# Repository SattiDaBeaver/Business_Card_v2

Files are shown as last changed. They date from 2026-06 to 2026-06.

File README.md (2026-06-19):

# RISC-V Supercluster Business Card

A business-card-sized PCB featuring a miniature distributed compute cluster with one master MCU coordinating eight worker nodes over a shared UART bus, powered and programmed entirely through a PCB-edge USB-C connector.

Inspired by distributed systems, Network-on-Chip architectures, and AI accelerator fabrics — shrunk down to fit in a wallet.

## Architecture

- **1× CH32X035F7P6** (master) — RV32IMAC, native USB 2.0 + USB PD PHY, USB CDC terminal, command parser, task scheduler, packet router
- **8× CH32V006F4P6** (workers) — RV32EC, distributed task execution, per-node LED, packet forwarding

## Communication

Workers and master share a half-duplex, open-drain UART bus (`BUS_MOSI` / `BUS_MISO`) with pull-up resistors to prevent contention. A simple addressed packet protocol (STX/DST/SRC/CMD/LEN/PAYLOAD/CRC8/ETX) handles routing, pings, LED control, and distributed compute tasks.

The master can individually reset and reflash any worker over UART using its factory bootloader — no physical programmer access needed after initial setup.

## Hardware Features

- USB-C via PCB edge connector (0.8mm board, no connector part needed)
- Shared 3.3V rail (AMS1117-3.3 LDO)
- Per-node SWIO/SDI debug pads for direct programming/recovery
- Individual master-controlled NRST per worker node
- Exposed GPIO test point grid on the reverse side

## Programming

- **Master:** USB bootloader or SWIO via WCH-LinkE
- **Workers:** SWIO via WCH-LinkE (initial flash) or UART bootloader via master (field updates)

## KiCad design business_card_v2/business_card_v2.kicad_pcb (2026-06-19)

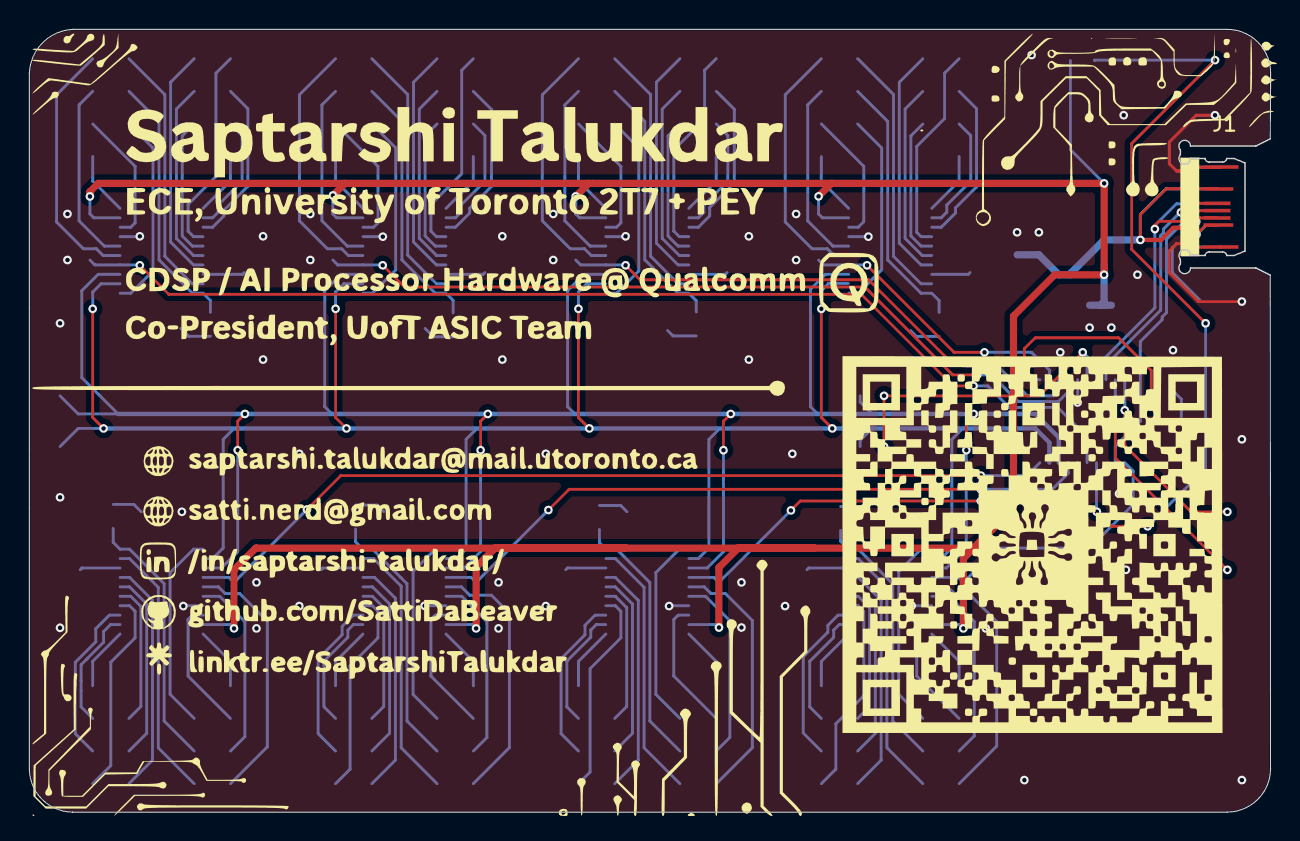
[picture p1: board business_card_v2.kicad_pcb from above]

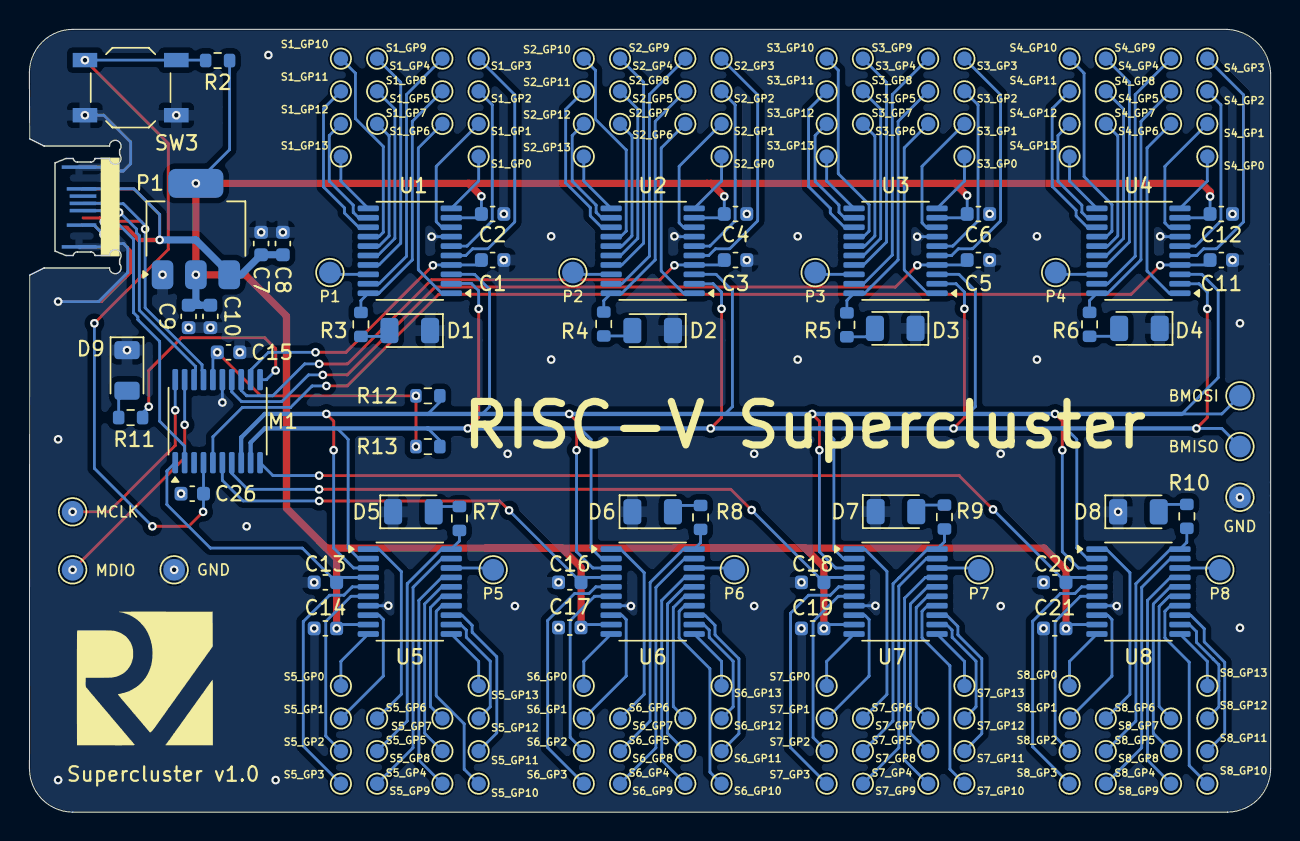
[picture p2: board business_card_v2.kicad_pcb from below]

Board: 2 copper layers, 85.6 x 54.0 mm, 181 parts (180 on the bottom side), 149 nets.

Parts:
BMISO: BUS_MISO; TestPoint_Pad_D1.5mm
BMOSI: BUS_MOSI; TestPoint_Pad_D1.5mm
C1, C2, C3, C4, C5, C6, C8, C9, C11, C12, C13, C14, C15, C16, C17, C18, C19, C20, C21, C26: 100nF; C_0603_1608Metric
C7, C10: 10uF; C_0603_1608Metric
D1, D2, D3, D4, D5, D6, D7, D8, D9: LED; LED_1206_3216Metric
GND: GND; TestPoint_Pad_D1.5mm
GND#2: GND; TestPoint_Pad_D1.5mm
J1: PCBTypeC_14P
M1: CH32X035F7P6; TSSOP-20_4.4x6.5mm_P0.65mm
MCLK: SWCLK_M; TestPoint_Pad_D1.5mm
MDIO: SWDIO_M; TestPoint_Pad_D1.5mm
P1: AMS1117-3.3; SOT-223-3_TabPin2
P1#2: SWIO_N1; TestPoint_Pad_D1.5mm
P2: SWIO_N2; TestPoint_Pad_D1.5mm
P3: SWIO_N3; TestPoint_Pad_D1.5mm
P4: SWIO_N4; TestPoint_Pad_D1.5mm
P5: SWIO_N5; TestPoint_Pad_D1.5mm
P6: SWIO_N6; TestPoint_Pad_D1.5mm
P7: SWIO_N7; TestPoint_Pad_D1.5mm
P8: SWIO_N8; TestPoint_Pad_D1.5mm
R2: 10k; R_0603_1608Metric
R3, R4, R5, R6, R7, R8, R9, R10, R11: 1k; R_0603_1608Metric
R12, R13: 5.1k; R_0603_1608Metric
S1_GP0, S1_GP1, S1_GP2, S1_GP3, S1_GP4, S1_GP5, S1_GP6, S1_GP7, S1_GP8, S1_GP9, S1_GP10, S1_GP11, S1_GP12, S1_GP13, S2_GP0, S2_GP1, S2_GP2, S2_GP3, S2_GP4, S2_GP5, S2_GP6, S2_GP7, S2_GP8, S2_GP9, S2_GP10, S2_GP11, S2_GP12, S2_GP13, S3_GP0, S3_GP1, S3_GP2, S3_GP3, S3_GP4, S3_GP5, S3_GP6, S3_GP7, S3_GP8, S3_GP9, S3_GP10, S3_GP11, S3_GP12, S3_GP13, S4_GP0, S4_GP1, S4_GP2, S4_GP3, S4_GP4, S4_GP5, S4_GP6, S4_GP7, S4_GP8, S4_GP9, S4_GP10, S4_GP11, S4_GP12, S4_GP13, S5_GP0, S5_GP1, S5_GP2, S5_GP3, S5_GP4, S5_GP5, S5_GP6, S5_GP7, S5_GP8, S5_GP9, S5_GP10, S5_GP11, S5_GP12, S5_GP13, S6_GP0, S6_GP1, S6_GP2, S6_GP3, S6_GP4, S6_GP5, S6_GP6, S6_GP7, S6_GP8, S6_GP9, S6_GP10, S6_GP11, S6_GP12, S6_GP13, S7_GP0, S7_GP1, S7_GP2, S7_GP3, S7_GP4, S7_GP5, S7_GP6, S7_GP7, S7_GP8, S7_GP9, S7_GP10, S7_GP11, S7_GP12, S7_GP13, S8_GP0, S8_GP1, S8_GP2, S8_GP3, S8_GP4, S8_GP5, S8_GP6, S8_GP7, S8_GP8, S8_GP9, S8_GP10, S8_GP11, S8_GP12, S8_GP13: TestPoint_Pad_D1.0mm
SW3: SW_Push; SW_SPST_TL3342
U1, U2, U3, U4, U5, U6, U7, U8: CH32V006F8P6; TSSOP-20_4.4x6.5mm_P0.65mm

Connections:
+3.3V: C2.2, C4.2, C6.2, C9.1, C10.1, C12.2, C14.2, C15.2, C17.2, C19.2, C21.2, M1.16 (VDD), P1.2 (VO), R2.2, R12.2, R13.2, U1.9 (VDD), U2.9 (VDD), U3.9 (VDD), U4.9 (VDD), U5.9 (VDD), U6.9 (VDD), U7.9 (VDD), U8.9 (VDD)
+5V: C7.1, C8.1, J1.A4 (VBUS), J1.A9 (VBUS), J1.B4 (VBUS), J1.B9 (VBUS), P1.3 (VI)
/BUS_MISO: BMISO.1 (1_1), M1.9 (PA3/RX2), R13.1, U1.2 (PD5/TX), U2.2 (PD5/TX), U3.2 (PD5/TX), U4.2 (PD5/TX), U5.2 (PD5/TX), U6.2 (PD5/TX), U7.2 (PD5/TX), U8.2 (PD5/TX)
/BUS_MOSI: BMOSI.1 (1_1), M1.8 (PA2/TX2), R12.1, U1.3 (PD6/RX), U2.3 (PD6/RX), U3.3 (PD6/RX), U4.3 (PD6/RX), U5.3 (PD6/RX), U6.3 (PD6/RX), U7.3 (PD6/RX), U8.3 (PD6/RX)
/CC1: J1.A5 (CC1), M1.2 (PC14/CC1)
/D+: J1.A6 (DP1), J1.B6 (DP2), M1.17 (PC16/UDM)
/D-: J1.A7 (DN1), J1.B7 (DN2), M1.18 (PC17/UDP)
/NRST_MASTER: C26.1, M1.4 (PC3/RST), R2.1, SW3.2
/NRST_S1: C1.1, M1.12 (PA6), U1.4 (PD7/RST)
/NRST_S2: C3.1, M1.13 (PA7), U2.4 (PD7/RST)
/NRST_S3: C5.1, M1.14 (PB1/RX4), U3.4 (PD7/RST)
/NRST_S4: C11.1, M1.5 (PC1), U4.4 (PD7/RST)
/NRST_S5: C13.1, M1.1 (PB12), U5.4 (PD7/RST)
/NRST_S6: C16.1, M1.6 (PA0), U6.4 (PD7/RST)
/NRST_S7: C18.1, M1.7 (PA1), U7.4 (PD7/RST)
/NRST_S8: C20.1, M1.10 (PA4), U8.4 (PD7/RST)
/SWCLK_M: M1.20 (PC19/DCK), MCLK.1 (1_1)
/SWDIO_M: M1.19 (PC18/DIO), MDIO.1 (1_1)
/SWIO_N1: P1#2.1 (1_1), U1.18 (PD1/SWIO)
/SWIO_N2: P2.1 (1_1), U2.18 (PD1/SWIO)
/SWIO_N3: P3.1 (1_1), U3.18 (PD1/SWIO)
/SWIO_N4: P4.1 (1_1), U4.18 (PD1/SWIO)
/SWIO_N5: P5.1 (1_1), U5.18 (PD1/SWIO)
/SWIO_N6: P6.1 (1_1), U6.18 (PD1/SWIO)
/SWIO_N7: P7.1 (1_1), U7.18 (PD1/SWIO)
/SWIO_N8: P8.1 (1_1), U8.18 (PD1/SWIO)
GND: C1.2, C2.1, C3.2, C4.1, C5.2, C6.1, C7.2, C8.2, C9.2, C10.2, C11.2, C12.1, C13.2, C14.1, C15.1, C16.2, C17.1, C18.2, C19.1, C20.2, C21.1, C26.2, D1.1 (K), D2.1 (K), D3.1 (K), D4.1 (K), D5.1 (K), D6.1 (K), D7.1 (K), D8.1 (K), D9.1 (K), GND.1 (1_1), GND#2.1 (1_1), J1.A1 (GND), J1.A12 (GND), J1.B1 (GND), J1.B12 (GND), M1.15 (GND), P1.1 (GND), SW3.1, U1.7 (VSS), U2.7 (VSS), U3.7 (VSS), U4.7 (VSS), U5.7 (VSS), U6.7 (VSS), U7.7 (VSS), U8.7 (VSS)
unnamed: D1.2 (A), R3.2
unnamed: D2.2 (A), R4.2
unnamed: D3.2 (A), R5.2
unnamed: D4.2 (A), R6.2
unnamed: D5.2 (A), R7.2
unnamed: D6.2 (A), R8.2
unnamed: D7.2 (A), R9.2
unnamed: D8.2 (A), R10.2
unnamed: D9.2 (A), R11.2
unnamed: M1.11 (PA5), R11.1
unnamed: S1_GP3.1 (1_1), U1.5 (PA1)
unnamed: S1_GP2.1 (1_1), U1.6 (PA2)
unnamed: S1_GP0.1 (1_1), U1.10 (PC0)
unnamed: S1_GP13.1 (1_1), U1.11 (PC1)
unnamed: S1_GP12.1 (1_1), U1.12 (PC2)
unnamed: S1_GP11.1 (1_1), U1.13 (PC3)
unnamed: S1_GP10.1 (1_1), U1.14 (PC4)
unnamed: S1_GP7.1 (1_1), U1.15 (PC5)
unnamed: S1_GP8.1 (1_1), U1.16 (PC6)
unnamed: S1_GP9.1 (1_1), U1.17 (PC7)
unnamed: S1_GP1.1 (1_1), U1.8 (PD0)
unnamed: S1_GP4.1 (1_1), U1.19 (PD2)
unnamed: R3.1, S1_GP5.1 (1_1), U1.20 (PD3)
unnamed: S1_GP6.1 (1_1), U1.1 (PD4)
unnamed: S2_GP3.1 (1_1), U2.5 (PA1)
unnamed: S2_GP2.1 (1_1), U2.6 (PA2)
unnamed: S2_GP0.1 (1_1), U2.10 (PC0)
unnamed: S2_GP13.1 (1_1), U2.11 (PC1)
unnamed: S2_GP12.1 (1_1), U2.12 (PC2)
unnamed: S2_GP11.1 (1_1), U2.13 (PC3)
unnamed: S2_GP10.1 (1_1), U2.14 (PC4)
unnamed: S2_GP7.1 (1_1), U2.15 (PC5)
unnamed: S2_GP8.1 (1_1), U2.16 (PC6)
unnamed: S2_GP9.1 (1_1), U2.17 (PC7)
unnamed: S2_GP1.1 (1_1), U2.8 (PD0)
unnamed: S2_GP4.1 (1_1), U2.19 (PD2)
unnamed: R4.1, S2_GP5.1 (1_1), U2.20 (PD3)
unnamed: S2_GP6.1 (1_1), U2.1 (PD4)
unnamed: S3_GP3.1 (1_1), U3.5 (PA1)
unnamed: S3_GP2.1 (1_1), U3.6 (PA2)
unnamed: S3_GP0.1 (1_1), U3.10 (PC0)
unnamed: S3_GP13.1 (1_1), U3.11 (PC1)
unnamed: S3_GP12.1 (1_1), U3.12 (PC2)
unnamed: S3_GP11.1 (1_1), U3.13 (PC3)
unnamed: S3_GP10.1 (1_1), U3.14 (PC4)
unnamed: S3_GP7.1 (1_1), U3.15 (PC5)
unnamed: S3_GP8.1 (1_1), U3.16 (PC6)
unnamed: S3_GP9.1 (1_1), U3.17 (PC7)
unnamed: S3_GP1.1 (1_1), U3.8 (PD0)
unnamed: S3_GP4.1 (1_1), U3.19 (PD2)
unnamed: R5.1, S3_GP5.1 (1_1), U3.20 (PD3)
unnamed: S3_GP6.1 (1_1), U3.1 (PD4)
unnamed: S4_GP3.1 (1_1), U4.5 (PA1)
unnamed: S4_GP2.1 (1_1), U4.6 (PA2)
unnamed: S4_GP0.1 (1_1), U4.10 (PC0)
unnamed: S4_GP13.1 (1_1), U4.11 (PC1)
unnamed: S4_GP12.1 (1_1), U4.12 (PC2)
unnamed: S4_GP11.1 (1_1), U4.13 (PC3)
unnamed: S4_GP10.1 (1_1), U4.14 (PC4)
unnamed: S4_GP7.1 (1_1), U4.15 (PC5)
unnamed: S4_GP8.1 (1_1), U4.16 (PC6)
unnamed: S4_GP9.1 (1_1), U4.17 (PC7)
unnamed: S4_GP1.1 (1_1), U4.8 (PD0)
unnamed: S4_GP4.1 (1_1), U4.19 (PD2)
unnamed: R6.1, S4_GP5.1 (1_1), U4.20 (PD3)
unnamed: S4_GP6.1 (1_1), U4.1 (PD4)
unnamed: S5_GP3.1 (1_1), U5.5 (PA1)
unnamed: S5_GP2.1 (1_1), U5.6 (PA2)
unnamed: S5_GP0.1 (1_1), U5.10 (PC0)
unnamed: S5_GP13.1 (1_1), U5.11 (PC1)
unnamed: S5_GP12.1 (1_1), U5.12 (PC2)
unnamed: S5_GP11.1 (1_1), U5.13 (PC3)
unnamed: S5_GP10.1 (1_1), U5.14 (PC4)
unnamed: S5_GP7.1 (1_1), U5.15 (PC5)
unnamed: S5_GP8.1 (1_1), U5.16 (PC6)
unnamed: S5_GP9.1 (1_1), U5.17 (PC7)
unnamed: S5_GP1.1 (1_1), U5.8 (PD0)
unnamed: S5_GP4.1 (1_1), U5.19 (PD2)
unnamed: R7.1, S5_GP5.1 (1_1), U5.20 (PD3)
unnamed: S5_GP6.1 (1_1), U5.1 (PD4)
unnamed: S6_GP3.1 (1_1), U6.5 (PA1)
unnamed: S6_GP2.1 (1_1), U6.6 (PA2)
unnamed: S6_GP0.1 (1_1), U6.10 (PC0)
unnamed: S6_GP13.1 (1_1), U6.11 (PC1)
unnamed: S6_GP12.1 (1_1), U6.12 (PC2)
unnamed: S6_GP11.1 (1_1), U6.13 (PC3)
unnamed: S6_GP10.1 (1_1), U6.14 (PC4)
unnamed: S6_GP7.1 (1_1), U6.15 (PC5)
unnamed: S6_GP8.1 (1_1), U6.16 (PC6)
unnamed: S6_GP9.1 (1_1), U6.17 (PC7)
unnamed: S6_GP1.1 (1_1), U6.8 (PD0)
unnamed: S6_GP4.1 (1_1), U6.19 (PD2)
unnamed: R8.1, S6_GP5.1 (1_1), U6.20 (PD3)
unnamed: S6_GP6.1 (1_1), U6.1 (PD4)
unnamed: S7_GP3.1 (1_1), U7.5 (PA1)
unnamed: S7_GP2.1 (1_1), U7.6 (PA2)
unnamed: S7_GP0.1 (1_1), U7.10 (PC0)
unnamed: S7_GP13.1 (1_1), U7.11 (PC1)
unnamed: S7_GP12.1 (1_1), U7.12 (PC2)
unnamed: S7_GP11.1 (1_1), U7.13 (PC3)
unnamed: S7_GP10.1 (1_1), U7.14 (PC4)
unnamed: S7_GP7.1 (1_1), U7.15 (PC5)
unnamed: S7_GP8.1 (1_1), U7.16 (PC6)
unnamed: S7_GP9.1 (1_1), U7.17 (PC7)
unnamed: S7_GP1.1 (1_1), U7.8 (PD0)
unnamed: S7_GP4.1 (1_1), U7.19 (PD2)
unnamed: R9.1, S7_GP5.1 (1_1), U7.20 (PD3)
unnamed: S7_GP6.1 (1_1), U7.1 (PD4)
unnamed: S8_GP3.1 (1_1), U8.5 (PA1)
unnamed: S8_GP2.1 (1_1), U8.6 (PA2)
unnamed: S8_GP0.1 (1_1), U8.10 (PC0)
unnamed: S8_GP13.1 (1_1), U8.11 (PC1)
unnamed: S8_GP12.1 (1_1), U8.12 (PC2)
unnamed: S8_GP11.1 (1_1), U8.13 (PC3)
unnamed: S8_GP10.1 (1_1), U8.14 (PC4)
unnamed: S8_GP7.1 (1_1), U8.15 (PC5)
unnamed: S8_GP8.1 (1_1), U8.16 (PC6)
unnamed: S8_GP9.1 (1_1), U8.17 (PC7)
unnamed: S8_GP1.1 (1_1), U8.8 (PD0)
unnamed: S8_GP4.1 (1_1), U8.19 (PD2)
unnamed: R10.1, S8_GP5.1 (1_1), U8.20 (PD3)
unnamed: S8_GP6.1 (1_1), U8.1 (PD4)

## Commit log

2026-05-29 created ch32 symbols. added PCB USBC, created board outline
    [business_card_v2.kicad_pcb, business_card_v2.kicad_sch]
2026-06-12 bottom left to top right pins
    [business_card_v2.kicad_pcb, business_card_v2.kicad_sch]
2026-06-12 9 S1 pins pattern
    [business_card_v2.kicad_pcb]
2026-06-14 added basic traces
    [business_card_v2.kicad_pcb, business_card_v2.kicad_sch]
2026-06-14 first commit: removed 1 MCU
    [business_card_v2.kicad_pcb, business_card_v2.kicad_sch]
2026-06-15 wired all GPIO
    [business_card_v2.kicad_pcb, business_card_v2.kicad_sch]
2026-06-16 added reset wires and bus
    [business_card_v2.kicad_pcb, business_card_v2.kicad_sch]
2026-06-19 finalized PCB
    [business_card_v2-B_Cu.gbr, business_card_v2-B_Mask.gbr, business_card_v2-B_Paste.gbr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]
